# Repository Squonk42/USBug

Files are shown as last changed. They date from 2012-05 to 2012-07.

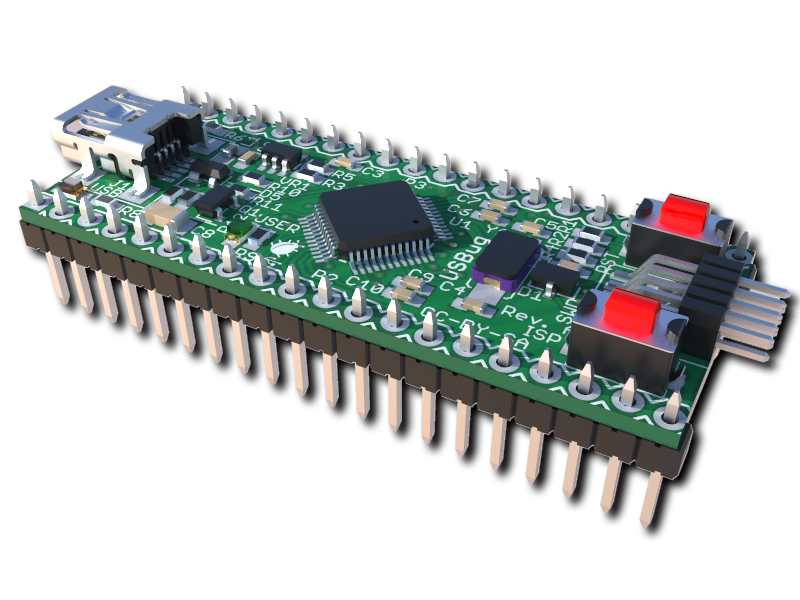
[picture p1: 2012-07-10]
images/USBug_Rendered.png

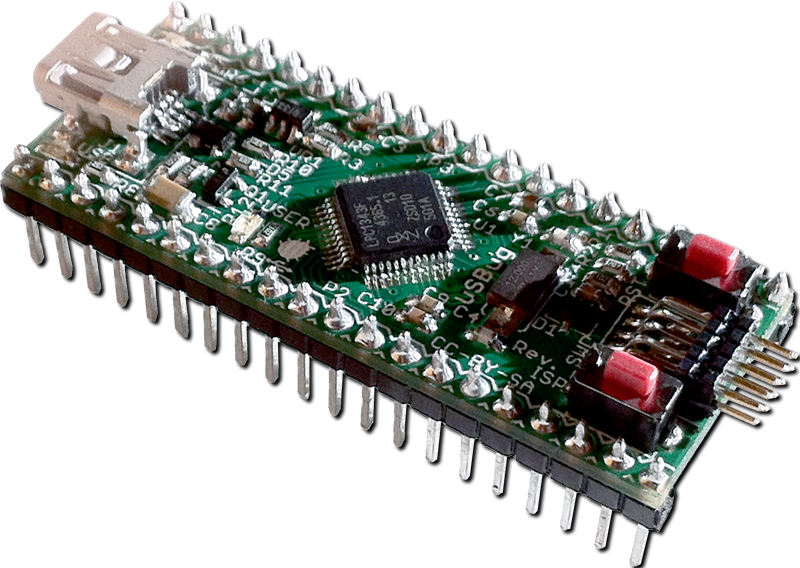
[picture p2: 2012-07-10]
images/USBug_Real.png

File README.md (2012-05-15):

USBug Development Board
=====

The USBug is a complete USB-based microcontroller development system in a very small footprint.
All programming is done via the USB port. No special programmer is needed, only a standard "Mini-B" USB cable and a Windows/Linux PC or a Macintosh with a USB port are required.

Key features:
 - Fully Open-Source Hardware & Software (CC-BY-SA, GPL)
 - Drag & Drop firmware, just use it as an USB Memory Stick!
 - No Loader application, the bootloader resides in ROM (unereasable)
 - Works with Mac OS X, Linux & Windows
 - Standard ARM SWD debug/trace connector
 - ARM "Cortex M3" 32-bit processor, up to 72 MHz, up to 64 kB Flash, up to 10 kB SRAM
 - Up to 42 GPIO pins, 1xUSB device, 1xUART, 1xI2C, 1xSPI interfaces
 - 2x32-bit, 2x16-bit, 1xWatchdog timers
 - 10 Bit ADC with up to 8 inputs
 - Tiny size: 2" x 0.8" (50 mm x 20 mm), only 0.244" (6.2 mm) thick (w/o header pins)
 - Available with pins for solderless breadboard
 - Very low cost & low shipping options

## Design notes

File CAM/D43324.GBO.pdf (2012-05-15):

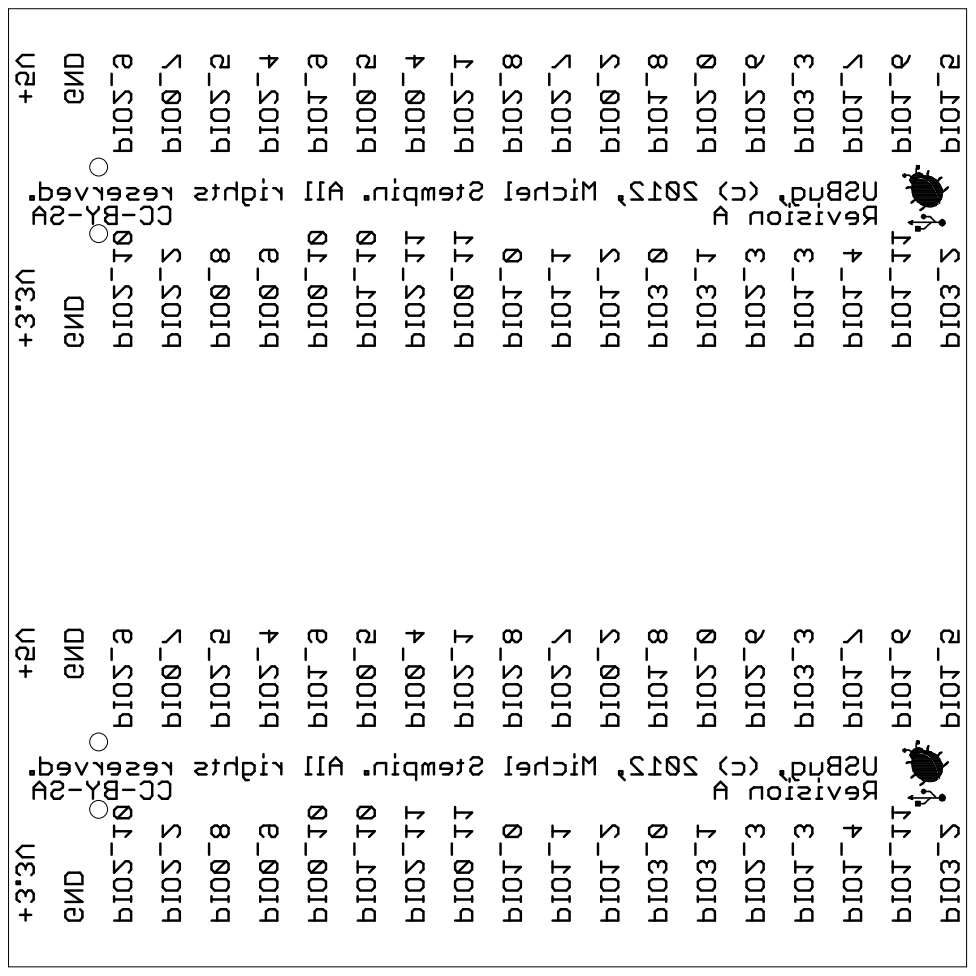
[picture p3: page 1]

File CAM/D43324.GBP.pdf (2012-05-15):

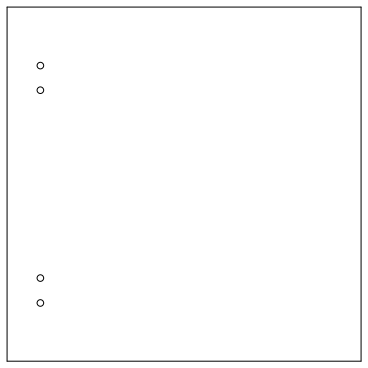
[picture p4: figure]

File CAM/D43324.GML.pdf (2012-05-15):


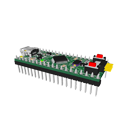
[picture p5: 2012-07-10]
images/USBug_Sketchup_s.png

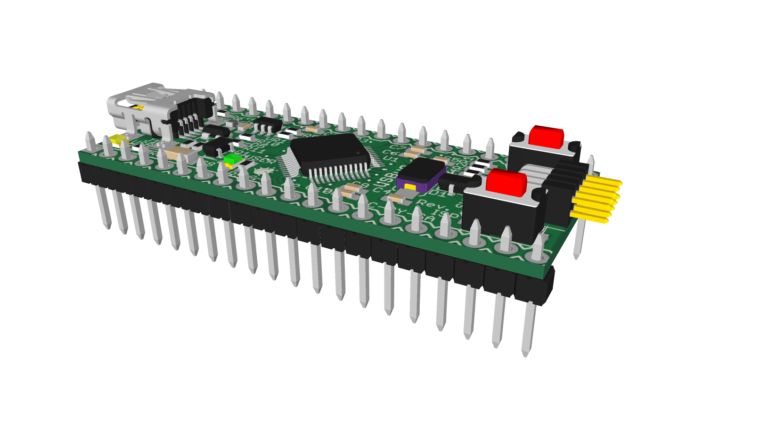
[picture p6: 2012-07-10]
images/USBug_Sketchup.png

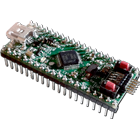
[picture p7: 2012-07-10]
images/USBug_Real_s.png

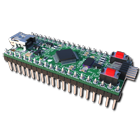
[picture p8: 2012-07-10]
images/USBug_Rendered_s.png

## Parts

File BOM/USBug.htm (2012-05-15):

Qty | Value | Device | Parts | Supplier | Supplier Part Number | Manufacturer | Manufacturer Part Number | Description | Price/1 | Price/50 | Price/100 | Price/250 | Price/500 | Price/1000
1 | 1M | RES_0603 | R12 | DigiKey | P1.0MGCT-ND | Panasonic - ECG | ERJ-3GEYJ105V | RES 1.0M OHM 1/10W 5% 0603 SMD | 0.10000 | 0.00920 | 0.00700 | 0.00520 | 0.00384 | 0.00256
2 | 1k | RES_0603 | R4, R9 | DigiKey | P1.0KGCT-ND | Panasonic - ECG | ERJ-3GEYJ102V | RES 1.0K OHM 1/10W 5% 0603 SMD | 0.10000 | 0.00920 | 0.00700 | 0.00520 | 0.00384 | 0.00256
1 | 1k5 | RES_0603 | R7 | DigiKey | P1.5KGCT-ND | Panasonic - ECG | ERJ-3GEYJ152V | RES 1.5K OHM 1/10W 5% 0603 SMD | 0.10000 | 0.00920 | 0.00700 | 0.00520 | 0.00384 | 0.00256
1 | 1u/16V | CAP_0603 | C2 | DigiKey | 587-1241-1-ND | Taiyo Yuden | EMK107B7105KA-T | CAP CER 1UF 16V 10% X7R 0603 | 0.20000 | 0.06000 | 0.04500 | 0.03252 | 0.02400 | 0.01625
1 | 2u2/10V | CAP_0603 | C3 | DigiKey | 587-2983-1-ND | Taiyo Yuden | LMK107B7225KA-T | CAP CER 2.2UF 10V 10% X7R 0603 | 0.32000 | 0.14000 | 0.11200 | 0.08000 | 0.05440 | 0.04400
1 | 10k | RES_0603 | R3 | DigiKey | P10KGCT-ND | Panasonic - ECG | ERJ-3GEYJ103V | RES 10K OHM 1/10W 5% 0603 SMD | 0.10000 | 0.00920 | 0.00700 | 0.00520 | 0.00384 | 0.00256
2 | 10n | CAP_0603 | C7, C10 | DigiKey | 445-6855-1-ND | TDK Corporation | C1608X7R1C103K | CAP CER 10000PF 16V 10% X7R 0603 | 0.24000 |  | 0.01100 | 0.00900 | 0.0770 | 0.00600
1 | 10n/500V | CAP_1206 | C8 | DigiKey | 709-1027-1-ND | Johanson Dielectrics Inc | 501R18W103KV4E | CAP CER 10000PF 500V X7R 1206 | 0.32000 |  | 0.11270 | 0.08052 | 0.05474 | 0.04428
1 | 12MHz | CRYSTAL_50X32 | Y1 | DigiKey | 644-1034-1-ND | NDK | NX5032GA-12.000000MHZ-LN-CD-1 | CRYSTAL 12.000000 MHZ 8PF SMD | 0.81000 | 0.61560 | 0.48600 |  | 0.41040
2 | 18p/50V | CAP_0603 | C4, C5 | DigiKey | 445-1272-1-ND | TDK Corporation | C1608C0G1H180J | CAP CER 18PF 50V 5% NP0 0603 | 0.30000 |  | 0.01380 | 0.01124 | 0.00962 | 0.00750
2 | 20K | RES_0603 | R1, R2 | DigiKey | P20KGCT-ND | Panasonic - ECG | ERJ-3GEYJ203V | RES 20K OHM 1/10W 5% 0603 SMD | 0.10000 | 0.00920 | 0.00700 | 0.00520 | 0.00384 | 0.00256
2 | 33R | RES_0603 | R10, R11 | DigiKey | P33GCT-ND | Panasonic - ECG | ERJ-3GEYJ330V | RES 33 OHM 1/10W 5% 0603 SMD | 0.10000 | 0.00920 | 0.00700 | 0.00520 | 0.00384 | 0.00256
1 | 100k | RES_0603 | R5 | DigiKey | P100KGCT-ND | Panasonic - ECG | ERJ-3GEYJ104V | RES 100K OHM 1/10W 5% 0603 SMD | 0.10000 | 0.00920 | 0.00700 | 0.00520 | 0.00384 | 0.00256
3 | 100n | CAP_0603 | C1, C6, C9 | DigiKey | 478-1239-1-ND | AVX Corporation | 0603YC104KAT2A | CAP CER 0.1UF 16V 10% X7R 0603 | 0.10000 |  | 0.00940 | 0.00764 | 0.00654 | 0.00500
2 | 150R | RES_0603 | R6, R8 | DigiKey | P150GCT-ND | Panasonic - ECG | ERJ-3GEYJ151V | RES 150 OHM 1/10W 5% 0603 SMD | 0.10000 | 0.00920 | 0.00700 | 0.00520 | 0.00384 | 0.00256
1 | BAT54C | BAT54C | D1 | DigiKey | BAT54C-FDICT-ND | Diodes Inc | BAT54C-7-F | DIODE SCHOTTKY DUAL 30V SOT23-3 | 0.20000 |  | 0.12050 | 0.07100 | 0.05890 | 0.04017
1 | BLM18EG601SN1D | FERRITE_BEAD0603 | L1 | DigiKey | 490-3994-1-ND | Murata Electronics North America | BLM18EG601SN1D | FILTER CHIP 600 OHM 500MA 0603 | 0.38000 | 0.21840 | 0.18200 | 0.13652 | 0.11648 | 0.09100
1 | BSS84-7-F | BSS84-7-F | Q1 | DigiKey | BSS84-FDICT-ND | Diodes Inc | BSS84-7-F | MOSFET P-CH 50V 130MA SOT23-3 | 0.39000 |  | 0.16380 | 0.11580 | 0.09270 | 0.07110
1 | FTSH-105-01-L-DH | FTSH-105-01-L-DH | P1 | DigiKey | SAM1160-05-ND | Samtec Inc | FTSH-105-01-L-DH | CONN HEADR 10POS DL .05" R/A SMD | 3.84000 |  | 2.81600 |  | 2.24000 | 1.82400
1 | ISP | SPST_SWITCH | S2 | DigiKey | 679-2307-1-ND | APEM Components, LLC | ADTSM32RVTR | SWITCH TACTILE SPST-NO 0.05A 12V | 0.86000 | 0.70100 | 0.61990 | 0.56596 | 0.53900
1 | LEFT | HEADER_1X20_LOCK | P2 | DigiKey | WM6420-ND | Molex Connector Corporation | 22-28-4200 | CONN HEADER 20POS .100 VERT TIN | 0.64000 |  | 0.47160 |  | 0.37276 | 0.32000
1 | LPC1343FBD48 | LPC1343FBD48 | U1 | DigiKey | 568-4945-ND | NXP Semiconductors | LPC1343FBD48,151 | IC MCU 32BIT 32KB FLASH 48LQFP | 4.51000 |  | 3.30050 | 2.97852 | 2.67260 | 2.25400
1 | MIC5225-3.3YM5 | MIC5225-3.3YM5 | VR1 | DigiKey | 576-2980-1-ND | Micrel Inc | MIC5225-3.3YM5 TR | IC REG 3.3V SOT23-5 | 0.75000 |  | 0.50000 | 0.37500 | 0.35000
1 | MINI-B USB | MINI-B_USBUX60-MB-5ST | J1 | DigiKey | H2959CT-ND | Hirose Electric Co Ltd | UX60-MB-5ST | CONN RECEPT MINI USB2.0 5POS | 1.25000 | 0.82500 | 0.74250 | 0.62700 | 0.52800
1 | POWER | LED_0805 | D2 | DigiKey | 350-2038-1-ND | Dialight | 598-8110-107F | LED TOPLED LED ALINGAP RED CLEAR 0805 SMD | 0.39000 |  | 0.16430 | 0.11624 | 0.09920 | 0.07750
1 | PRTR5V0U2X | PRTR5V0U2X | D5 | DigiKey | 568-4140-1-ND | NXP Semiconductors | PRTR5V0U2X,215 | DIODE ESD PROTECTION SOT143B | 0.57000 |  | 0.35780 | 0.31036 | 0.26286 | 0.20265
1 | RESET | SPST_SWITCH | S1 | DigiKey | 679-2307-1-ND | APEM Components, LLC | ADTSM32RVTR | SWITCH TACTILE SPST-NO 0.05A 12V | 0.86000 | 0.70100 | 0.61990 | 0.56596 | 0.53900
1 | RIGHT | HEADER_1X20_LOCK | P3 | DigiKey | WM6420-ND | Molex Connector Corporation | 22-28-4200 | CONN HEADER 20POS .100 VERT TIN | 0.64000 |  | 0.47160 |  | 0.37276 | 0.32000
1 | USB | LED_0805 | D3 | DigiKey | 350-2032-1-ND | Dialight | 598-8140-107F | LED ALINGAP YLW CLEAR 0805 SMD | 0.46000 |  | 0.19610 | 0.13876 | 0.11840 | 0.09250
1 | USBUG | USBUG | LOGO
1 | USER | LED_0805 | D4 | DigiKey | 350-2035-1-ND | Dialight | 598-8170-107F | LED ALINGAP GREEN CLEAR 0805 SMD | 0.41000 |  | 0.17490 | 0.12376 | 0.10560 | 0.08250

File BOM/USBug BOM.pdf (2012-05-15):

# USBug

Qty | Value | Device | Parts | Supplier | Supplier Part Number | Supplier Part Number | Manufacturer | Manufacturer Part Number | Description | Price/1 | Price/50 | Price/100 | Price/250 | Price/500 | Price/1000 | Total/1
3 | 100n | CAP_0603 | C1, C6, C9 | DigiKey | 478-1239-1-ND | 478-1239-6-ND | AVX Corporation | 0603YC104KAT2A | CAP CER 0.1UF 16V 10% X7R 0603 | $0,10000 | | $0,00940 | $0,00764 | $0,00654 | $0,00500 | $0,30000
1 | 1u/16V | CAP_0603 | C2 | DigiKey | 587-1241-1-ND | 587-1241-6-ND | Taiyo Yuden | EMK107B7105KA-T | CAP CER 1UF 16V 10% X7R 0603 | $0,20000 | $0,06000 | $0,04500 | $0,03252 | $0,02400 | $0,01625 | $0,20000
1 | 2u2/10V | CAP_0603 | C3 | DigiKey | 587-2983-1-ND | 587-2983-6-ND | Taiyo Yuden | LMK107B7225KA-T | CAP CER 2.2UF 10V 10% X7R 0603 | $0,32000 | $0,14000 | $0,11200 | $0,08000 | $0,05440 | $0,04400 | $0,32000
2 | 18p | CAP_0603 | C4, C5 | DigiKey | 445-1272-1-ND | 445-1272-6-ND | TDK Corporation | C1608C0G1H180J | CAP CER 18PF 50V 5% NP0 0603 | $0,30000 | | $0,01380 | $0,01124 | $0,00962 | $0,00750 | $0,60000
2 | 10n | CAP_0603 | C7, C10 | DigiKey | 445-6855-1-ND | 445-6855-6-ND | TDK Corporation | C1608X7R1C103K | CAP CER 10000PF 16V 10% X7R 0603 | $0,24000 | | $0,01100 | $0,00900 | $0,00770 | $0,00600 | $0,48000
1 | 10n/500V | CAP_1206 | C8 | DigiKey | 709-1027-1-ND | 709-1027-6-ND | Johanson Dielectrics Inc | 501R18W103KV4E | CAP CER 10000PF 500V X7R 1206 | $0,32000 | | $0,11270 | $0,08052 | $0,05474 | $0,04428 | $0,32000
1 | BAT54C | BAT54C | D1 | DigiKey | BAT54C-FDICT-ND | BAT54C-FDIDKR-ND | Diodes Inc | BAT54C-7-F | DIODE SCHOTTKY DUAL 30V SOT23-3 | $0,20000 | | $0,12050 | $0,07100 | $0,05890 | $0,04017 | $0,20000
1 | POWER | LED_0805 | D2 | DigiKey | 350-2038-1-ND | 350-2038-1-ND | Dialight | 598-8110-107F | LED ALINGAP RED CLEAR 0805 SMD | $0,39000 | | $0,16430 | $0,11624 | $0,09920 | $0,07750 | $0,39000
1 | USB | LED_0805 | D3 | DigiKey | 350-2032-1-ND | 350-2032-1-ND | Dialight | 598-8140-107F | LED ALINGAP YLW CLEAR 0805 SMD | $0,46000 | | $0,19610 | $0,13876 | $0,11840 | $0,09250 | $0,46000
1 | USER | LED_0805 | D4 | DigiKey | 350-2035-1-ND | 350-2035-1-ND | Dialight | 598-8170-107F | LED ALINGAP GREEN CLEAR 0805 SMD | $0,41000 | | $0,17490 | $0,12376 | $0,10560 | $0,08250 | $0,41000
1 | PRTR5V0U2X | PRTR5V0U2X | D5 | DigiKey | 568-4140-1-ND | 568-4140-6-ND | NXP Semiconductors | PRTR5V0U2X,215 | DIODE ESD PROTECTION SOT143B | $0,57000 | | $0,35780 | $0,31036 | $0,26286 | $0,20265 | $0,57000
1 | MINI-B USB | MINI-B_USBUX60-MB-5ST | J1 | DigiKey | H2959CT-ND | H2959DKR-ND | Hirose Electric Co Ltd | UX60-MB-5ST | CONN RECEPT MINI USB2.0 5POS | $1,25000 | $0,82500 | $0,74250 | $0,62700 | $0,52800 | $0,52800 | $1,25000
1 | BLM18EG601SN1D | FERRITE_BEAD0603 | L1 | DigiKey | 490-3994-1-ND | 490-3994-6-ND | Murata Electronics North America | BLM18EG601SN1D | FILTER CHIP 600 OHM 500MA 0603 | $0,38000 | $0,21840 | $0,18200 | $0,13652 | $0,11648 | $0,09100 | $0,38000
1 | FTSH-105-01-L-DH | FTSH-105-01-L-DH | P1 | DigiKey | SAM1160-05-ND | SAM1160-05-ND | Samtec Inc | FTSH-105-01-L-DH | CONN HEADR 10POS DL .05" R/A SMD | $3,84000 | | $2,81600 | | $2,24000 | $1,82400 | $3,84000
1 | LEFT | HEADER_1X20_LOCK | P2 | DigiKey | WM6420-ND | WM6420-ND | Molex Connector Corporation | 22-28-4200 | CONN HEADER 20POS .100 VERT TIN | $0,64000 | | $0,47160 | | $0,37276 | $0,32000 | $0,64000
1 | RIGHT | HEADER_1X20_LOCK | P3 | DigiKey | WM6420-ND | WM6420-ND | Molex Connector Corporation | 22-28-4200 | CONN HEADER 20POS .100 VERT TIN | $0,64000 | | $0,47160 | | $0,37276 | $0,32000 | $0,64000
1 | BSS84-7-F | BSS84-7-F | Q1 | DigiKey | BSS84-FDICT-ND | BSS84-FDIDKR-ND | Diodes Inc | BSS84-7-F | MOSFET P-CH 50V 130MA SOT23-3 | $0,39000 | | $0,16380 | $0,11580 | $0,09270 | $0,07110 | $0,39000
2 | 20K | RES_0603 | R1, R2 | DigiKey | P20KGCT-ND | P20KGDKR-ND | Panasonic - ECG | ERJ-3GEYJ203V | RES 20K OHM 1/10W 5% 0603 SMD | $0,10000 | $0,00920 | $0,00700 | $0,00520 | $0,00384 | $0,00256 | $0,20000
2 | 33R | RES_0603 | R10, R11 | DigiKey | P33GCT-ND | P33GDKR-ND | Panasonic - ECG | ERJ-3GEYJ330V | RES 33 OHM 1/10W 5% 0603 SMD | $0,10000 | $0,00920 | $0,00700 | $0,00520 | $0,00384 | $0,00256 | $0,20000
1 | 1M | RES_0603 | R12 | DigiKey | P1.0MGCT-ND | P1.0MGDKR-ND | Panasonic - ECG | ERJ-3GEYJ105V | RES 1.0M OHM 1/10W 5% 0603 SMD | $0,10000 | $0,00920 | $0,00700 | $0,00520 | $0,00384 | $0,00256 | $0,10000
1 | 10k | RES_0603 | R3 | DigiKey | P10KGCT-ND | P10KGDKR-ND | Panasonic - ECG | ERJ-3GEYJ103V | RES 10K OHM 1/10W 5% 0603 SMD | $0,10000 | $0,00920 | $0,00700 | $0,00520 | $0,00384 | $0,00256 | $0,10000
2 | 1k | RES_0603 | R4, R9 | DigiKey | P1.0KGCT-ND | P1.0KGDKR-ND | Panasonic - ECG | ERJ-3GEYJ102V | RES 1.0K OHM 1/10W 5% 0603 SMD | $0,10000 | $0,00920 | $0,00700 | $0,00520 | $0,00384 | $0,00256 | $0,20000
1 | 100k | RES_0603 | R5 | DigiKey | P100KGCT-ND | P100KGDKR-ND | Panasonic - ECG | ERJ-3GEYJ104V | RES 100K OHM 1/10W 5% 0603 SMD | $0,10000 | $0,00920 | $0,00700 | $0,00520 | $0,00384 | $0,00256 | $0,10000
2 | 150R | RES_0603 | R6, R8 | DigiKey | P150GCT-ND | P150GDKR-ND | Panasonic - ECG | ERJ-3GEYJ151V | RES 150 OHM 1/10W 5% 0603 SMD | $0,10000 | $0,00920 | $0,00700 | $0,00520 | $0,00384 | $0,00256 | $0,20000
1 | 1k5 | RES_0603 | R7 | DigiKey | P1.5KGCT-ND | P1.5KGDKR-ND | Panasonic - ECG | ERJ-3GEYJ152V | RES 1.5K OHM 1/10W 5% 0603 SMD | $0,10000 | $0,00920 | $0,00700 | $0,00520 | $0,00384 | $0,00256 | $0,10000
1 | RESET | SPST_SWITCH | S1 | DigiKey | 679-2307-1-ND | 679-2307-6-ND | APEM Components, LLC | ADTSM32RVTR | SWITCH TACTILE SPST-NO 0.05A 12V | $0,86000 | $0,00920 | $0,00700 | $0,00520 | $0,00384 | $0,00256 | $0,86000
1 | ISP | SPST_SWITCH | S2 | DigiKey | 679-2307-1-ND | 679-2307-6-ND | APEM Components, LLC | ADTSM32RVTR | SWITCH TACTILE SPST-NO 0.05A 12V | $0,86000 | $0,70100 | $0,61990 | $0,56596 | $0,53900 | $0,53900 | $0,86000
1 | LPC1343FBD48 | LPC1343FBD48 | U1 | DigiKey | 568-4945-ND | 568-4945-ND | NXP Semiconductors | LPC1343FBD48,151 | IC MCU 32BIT 32KB FLASH 48LQFP | $4,51000 | | $3,30050 | $2,97852 | $2,67260 | $2,25400 | $4,51000
1 | MIC5225-3.3YM5 | MIC5225-3.3YM5 | VR1 | DigiKey | 576-2980-1-ND | 576-2980-6-ND | Micrel Inc | MIC5225-3.3YM5 TR | IC REG 3.3V SOT23-5 | $0,75000 | | $0,50000 | $0,37500 | $0,35000 | $0,35000 | $0,75000
1 | 12MHz | CRYSTAL_50X32 | Y1 | DigiKey | 644-1034-1-ND | 644-1034-6-ND | NDK | NX5032GA-12.000000MHZ-LN-CD-1 | CRYSTAL 12.000000 MHZ 8PF SMD | $0,81000 | $0,61560 | $0,48600 | | $0,41040 | $0,41040 | $0,81000
TOTAL | | | | | | | | | | | | | | | | $19,88000
Michel Stempin | Page 1 | 15/05/2012

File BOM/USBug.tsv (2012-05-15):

Key | Supplier | Supplier Part Number | Manufacturer | Manufacturer Part Number | Description | Price/1 | Price/50 | Price/100 | Price/250 | Price/500 | Price/1000
FERRITE_BEAD0603:BLM18EG601SN1D | DigiKey | 490-3994-1-ND | Murata Electronics North America | BLM18EG601SN1D | FILTER CHIP 600 OHM 500MA 0603 | 0.38000 | 0.21840 | 0.18200 | 0.13652 | 0.11648 | 0.09100
BSS84-7-F | DigiKey | BSS84-FDICT-ND | Diodes Inc | BSS84-7-F | MOSFET P-CH 50V 130MA SOT23-3 | 0.39000 |  | 0.16380 | 0.11580 | 0.09270 | 0.07110
FTSH-105-01-L-DH | DigiKey | SAM1160-05-ND | Samtec Inc | FTSH-105-01-L-DH | CONN HEADR 10POS DL .05" R/A SMD | 3.84000 |  | 2.81600 |  | 2.24000 | 1.82400
MIC5225-3.3YM5 | DigiKey | 576-2980-1-ND | Micrel Inc | MIC5225-3.3YM5 TR | IC REG 3.3V SOT23-5 | 0.75000 |  | 0.50000 | 0.37500 | 0.35000
PRTR5V0U2X | DigiKey | 568-4140-1-ND | NXP Semiconductors | PRTR5V0U2X,215 | DIODE ESD PROTECTION SOT143B | 0.57000 |  | 0.35780 | 0.31036 | 0.26286 | 0.20265
CRYSTAL_50X32:12MHz | DigiKey | 644-1034-1-ND | NDK | NX5032GA-12.000000MHZ-LN-CD-1 | CRYSTAL 12.000000 MHZ 8PF SMD | 0.81000 | 0.61560 | 0.48600 |  | 0.41040
MINI-B_USBUX60-MB-5ST:MINI-B USB | DigiKey | H2959CT-ND | Hirose Electric Co Ltd | UX60-MB-5ST | CONN RECEPT MINI USB2.0 5POS | 1.25000 | 0.82500 | 0.74250 | 0.62700 | 0.52800
HEADER_1X20_LOCK:LEFT | DigiKey | WM6420-ND | Molex Connector Corporation | 22-28-4200 | CONN HEADER 20POS .100 VERT TIN | 0.64000 |  | 0.47160 |  | 0.37276 | 0.32000
HEADER_1X20_LOCK:RIGHT | DigiKey | WM6420-ND | Molex Connector Corporation | 22-28-4200 | CONN HEADER 20POS .100 VERT TIN | 0.64000 |  | 0.47160 |  | 0.37276 | 0.32000
SPST_SWITCH:ISP | DigiKey | 679-2307-1-ND | APEM Components, LLC | ADTSM32RVTR | SWITCH TACTILE SPST-NO 0.05A 12V | 0.86000 | 0.70100 | 0.61990 | 0.56596 | 0.53900
SPST_SWITCH:RESET | DigiKey | 679-2307-1-ND | APEM Components, LLC | ADTSM32RVTR | SWITCH TACTILE SPST-NO 0.05A 12V | 0.86000 | 0.70100 | 0.61990 | 0.56596 | 0.53900
BAT54C | DigiKey | BAT54C-FDICT-ND | Diodes Inc | BAT54C-7-F | DIODE SCHOTTKY DUAL 30V SOT23-3 | 0.20000 |  | 0.12050 | 0.07100 | 0.05890 | 0.04017
LED_0805:POWER | DigiKey | 350-2038-1-ND | Dialight | 598-8110-107F | LED TOPLED LED ALINGAP RED CLEAR 0805 SMD | 0.39000 |  | 0.16430 | 0.11624 | 0.09920 | 0.07750
LED_0805:USB | DigiKey | 350-2032-1-ND | Dialight | 598-8140-107F | LED ALINGAP YLW CLEAR 0805 SMD | 0.46000 |  | 0.19610 | 0.13876 | 0.11840 | 0.09250
LED_0805:USER | DigiKey | 350-2035-1-ND | Dialight | 598-8170-107F | LED ALINGAP GREEN CLEAR 0805 SMD | 0.41000 |  | 0.17490 | 0.12376 | 0.10560 | 0.08250
LPC11U12FBD48 | DigiKey | 568-8582-ND | NXP Semiconductors | LPC11U12FBD48/201, | IC MCU 32BIT 16K 48LQFP | 3.61000 |  | 2.64450 | 2.38652 | 2.14140 | 1.80600
RES_0603:1M | DigiKey | P1.0MGCT-ND | Panasonic - ECG | ERJ-3GEYJ105V | RES 1.0M OHM 1/10W 5% 0603 SMD | 0.10000 | 0.00920 | 0.00700 | 0.00520 | 0.00384 | 0.00256
RES_0603:1k5 | DigiKey | P1.5KGCT-ND | Panasonic - ECG | ERJ-3GEYJ152V | RES 1.5K OHM 1/10W 5% 0603 SMD | 0.10000 | 0.00920 | 0.00700 | 0.00520 | 0.00384 | 0.00256
RES_0603:20K | DigiKey | P20KGCT-ND | Panasonic - ECG | ERJ-3GEYJ203V | RES 20K OHM 1/10W 5% 0603 SMD | 0.10000 | 0.00920 | 0.00700 | 0.00520 | 0.00384 | 0.00256
RES_0603:10k | DigiKey | P10KGCT-ND | Panasonic - ECG | ERJ-3GEYJ103V | RES 10K OHM 1/10W 5% 0603 SMD | 0.10000 | 0.00920 | 0.00700 | 0.00520 | 0.00384 | 0.00256
RES_0603:1k | DigiKey | P1.0KGCT-ND | Panasonic - ECG | ERJ-3GEYJ102V | RES 1.0K OHM 1/10W 5% 0603 SMD | 0.10000 | 0.00920 | 0.00700 | 0.00520 | 0.00384 | 0.00256
RES_0603:100k | DigiKey | P100KGCT-ND | Panasonic - ECG | ERJ-3GEYJ104V | RES 100K OHM 1/10W 5% 0603 SMD | 0.10000 | 0.00920 | 0.00700 | 0.00520 | 0.00384 | 0.00256
RES_0603:150R | DigiKey | P150GCT-ND | Panasonic - ECG | ERJ-3GEYJ151V | RES 150 OHM 1/10W 5% 0603 SMD | 0.10000 | 0.00920 | 0.00700 | 0.00520 | 0.00384 | 0.00256
RES_0603:33R | DigiKey | P33GCT-ND | Panasonic - ECG | ERJ-3GEYJ330V | RES 33 OHM 1/10W 5% 0603 SMD | 0.10000 | 0.00920 | 0.00700 | 0.00520 | 0.00384 | 0.00256
CAP_0603:100n | DigiKey | 478-1239-1-ND | AVX Corporation | 0603YC104KAT2A | CAP CER 0.1UF 16V 10% X7R 0603 | 0.10000 |  | 0.00940 | 0.00764 | 0.00654 | 0.00500
CAP_0603:10n | DigiKey | 445-6855-1-ND | TDK Corporation | C1608X7R1C103K | CAP CER 10000PF 16V 10% X7R 0603 | 0.24000 |  | 0.01100 | 0.00900 | 0.0770 | 0.00600
CAP_0603:1u/16V | DigiKey | 587-1241-1-ND | Taiyo Yuden | EMK107B7105KA-T | CAP CER 1UF 16V 10% X7R 0603 | 0.20000 | 0.06000 | 0.04500 | 0.03252 | 0.02400 | 0.01625
CAP_0603:2u2/10V | DigiKey | 587-2983-1-ND | Taiyo Yuden | LMK107B7225KA-T | CAP CER 2.2UF 10V 10% X7R 0603 | 0.32000 | 0.14000 | 0.11200 | 0.08000 | 0.05440 | 0.04400
CAP_0603:18p/50V | DigiKey | 445-1272-1-ND | TDK Corporation | C1608C0G1H180J | CAP CER 18PF 50V 5% NP0 0603 | 0.30000 |  | 0.01380 | 0.01124 | 0.00962 | 0.00750
CAP_1206:10n/500V | DigiKey | 709-1027-1-ND | Johanson Dielectrics Inc | 501R18W103KV4E | CAP CER 10000PF 500V X7R 1206 | 0.32000 |  | 0.11270 | 0.08052 | 0.05474 | 0.04428
LPC1343FBD48 | DigiKey | 568-4945-ND | NXP Semiconductors | LPC1343FBD48,151 | IC MCU 32BIT 32KB FLASH 48LQFP | 4.51000 |  | 3.30050 | 2.97852 | 2.67260 | 2.25400

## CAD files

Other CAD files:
eagleUp/USBug.skp

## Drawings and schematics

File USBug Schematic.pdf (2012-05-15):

A

A

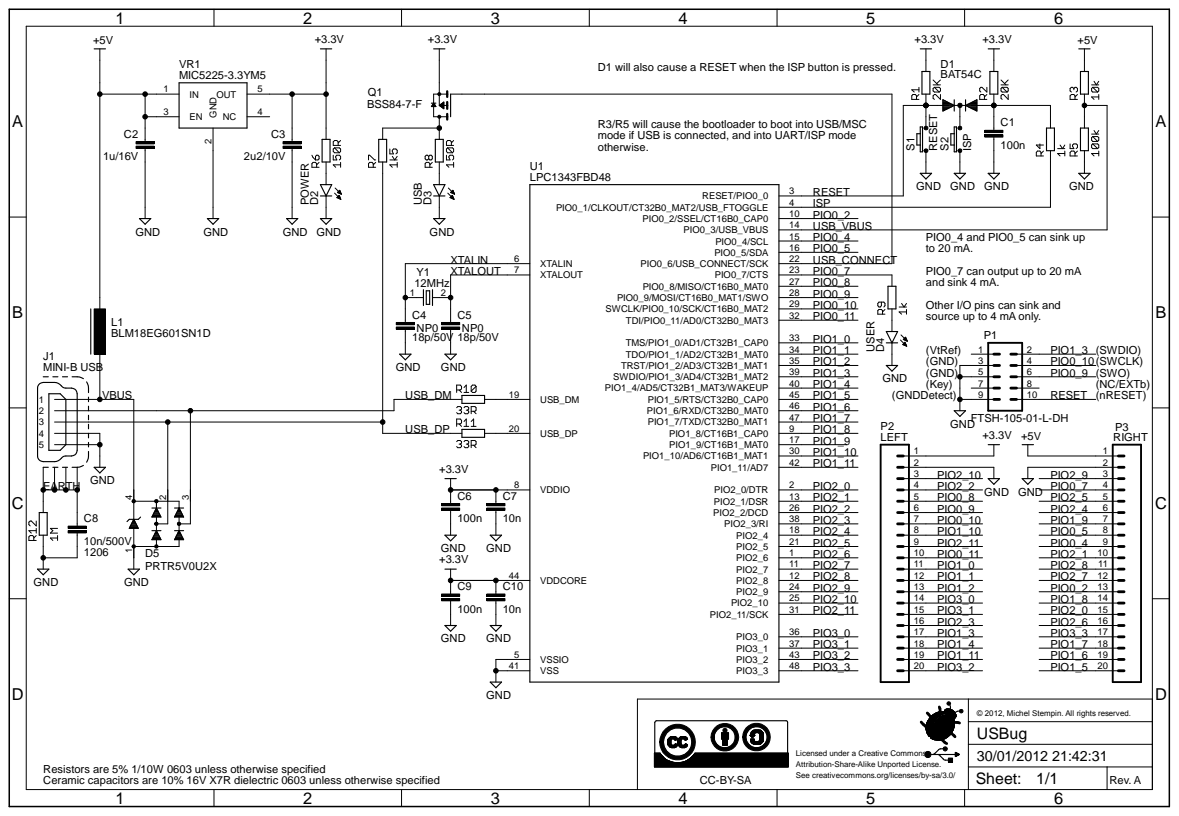
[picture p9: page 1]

D1 will also cause a RESET when the ISP button is pressed.

R3/R5 will cause the bootloader to boot into USB/MS
mode if USB is connected, and into UART/ISP mode
otherwise.

PIO0_4 and PIO0_5 can sink up
PIO0_7 can output up to 20 mA
and sink 4 mA.
Other I/O pins can sink and
source up to 4 mA only.

Licensed under a Creative Commons
Attribution-Share-Alike Unported License.
See creativecommons.org/licenses/by-sa/3.0/

Resistors are 5% 1/10W 0603 unless otherwise specified
Ceramic capacitors are 10% 16V X7R dielectric 0603 unless otherwise specified

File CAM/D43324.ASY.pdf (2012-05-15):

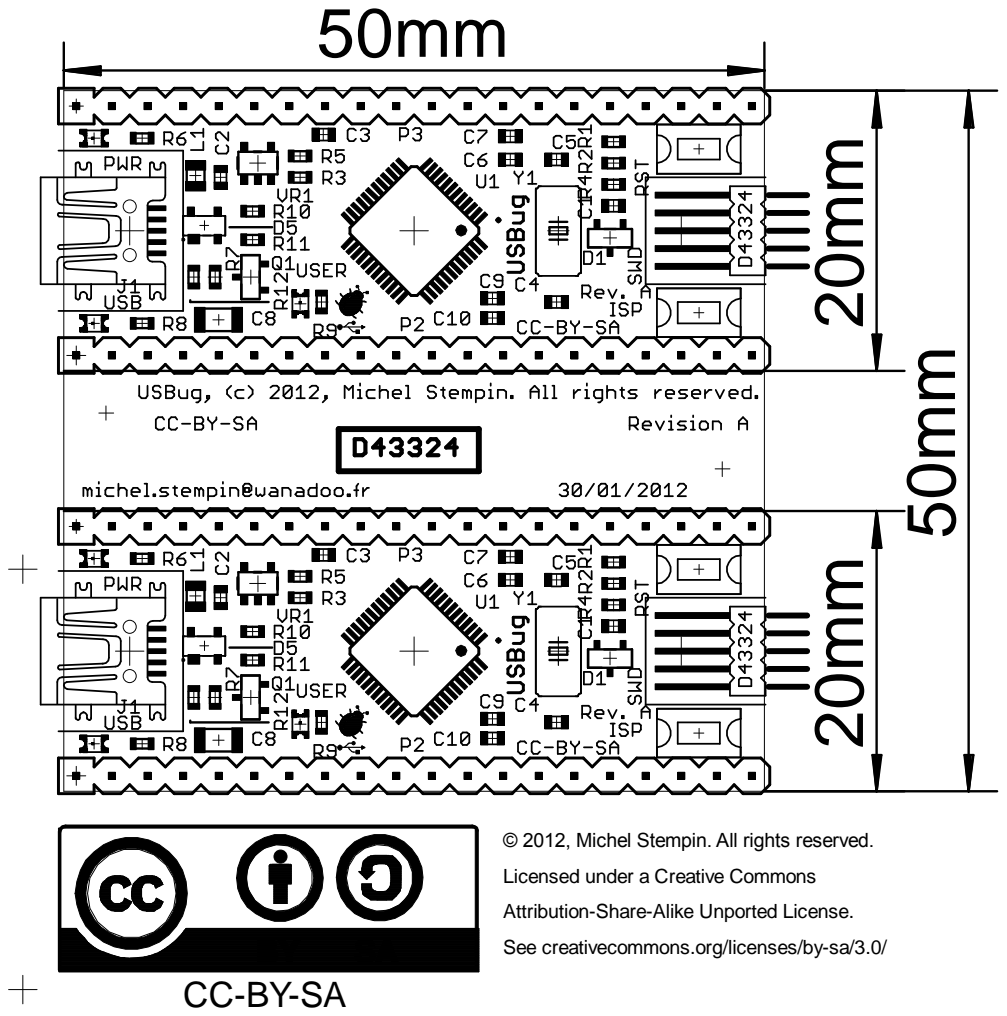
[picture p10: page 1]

© 2012, Michel Stempin. All rights reserved.
Licensed under a Creative Commons
Attribution-Share-Alike Unported License.
See creativecommons.org/licenses/by-sa/3.0/

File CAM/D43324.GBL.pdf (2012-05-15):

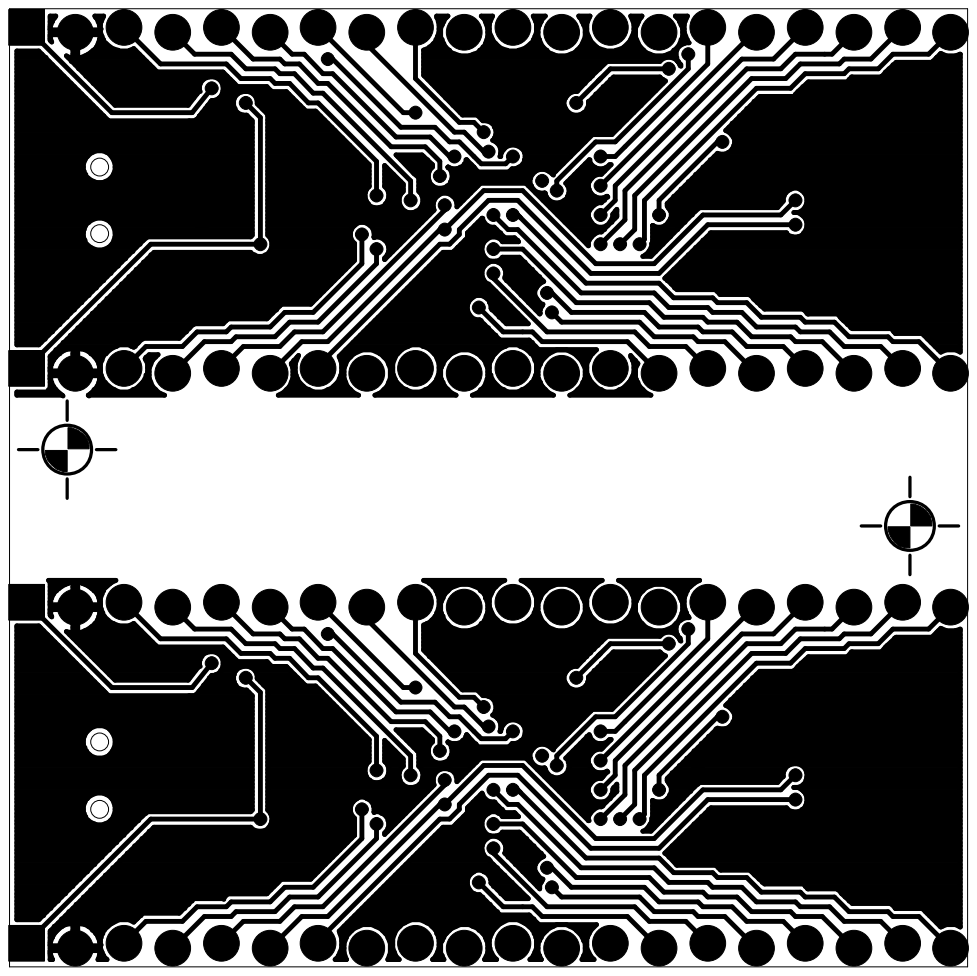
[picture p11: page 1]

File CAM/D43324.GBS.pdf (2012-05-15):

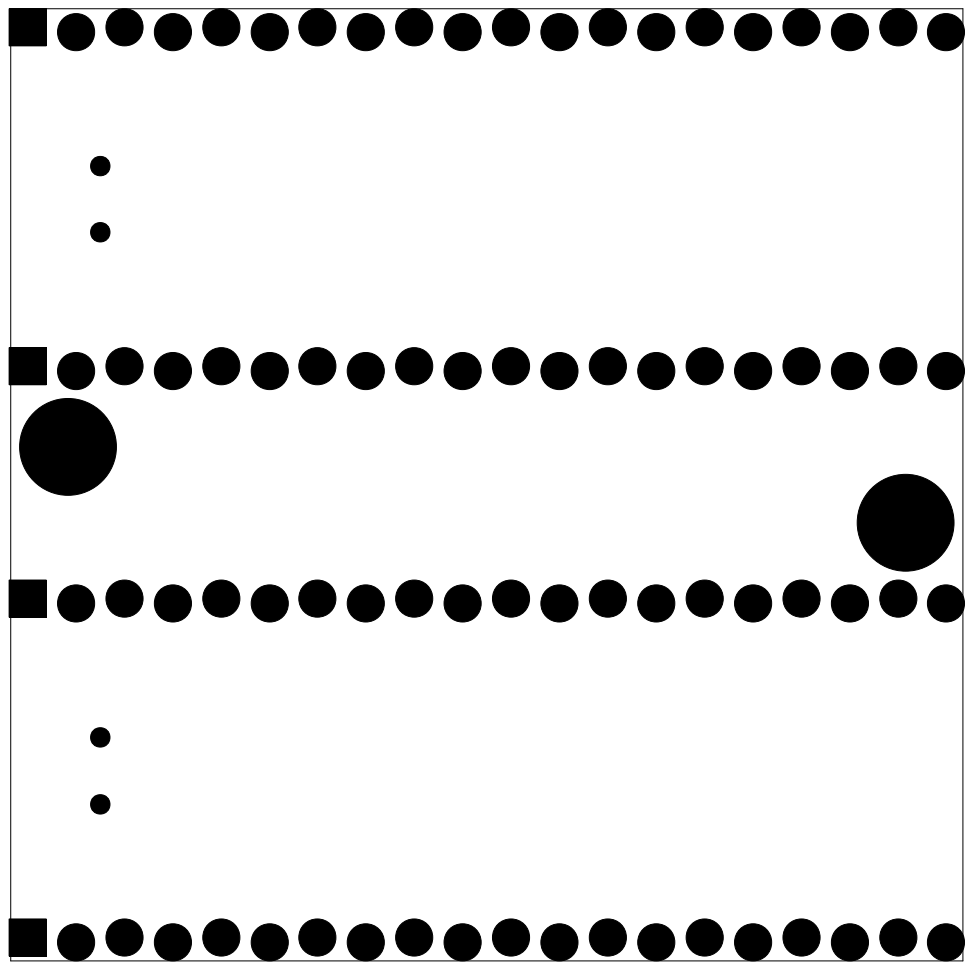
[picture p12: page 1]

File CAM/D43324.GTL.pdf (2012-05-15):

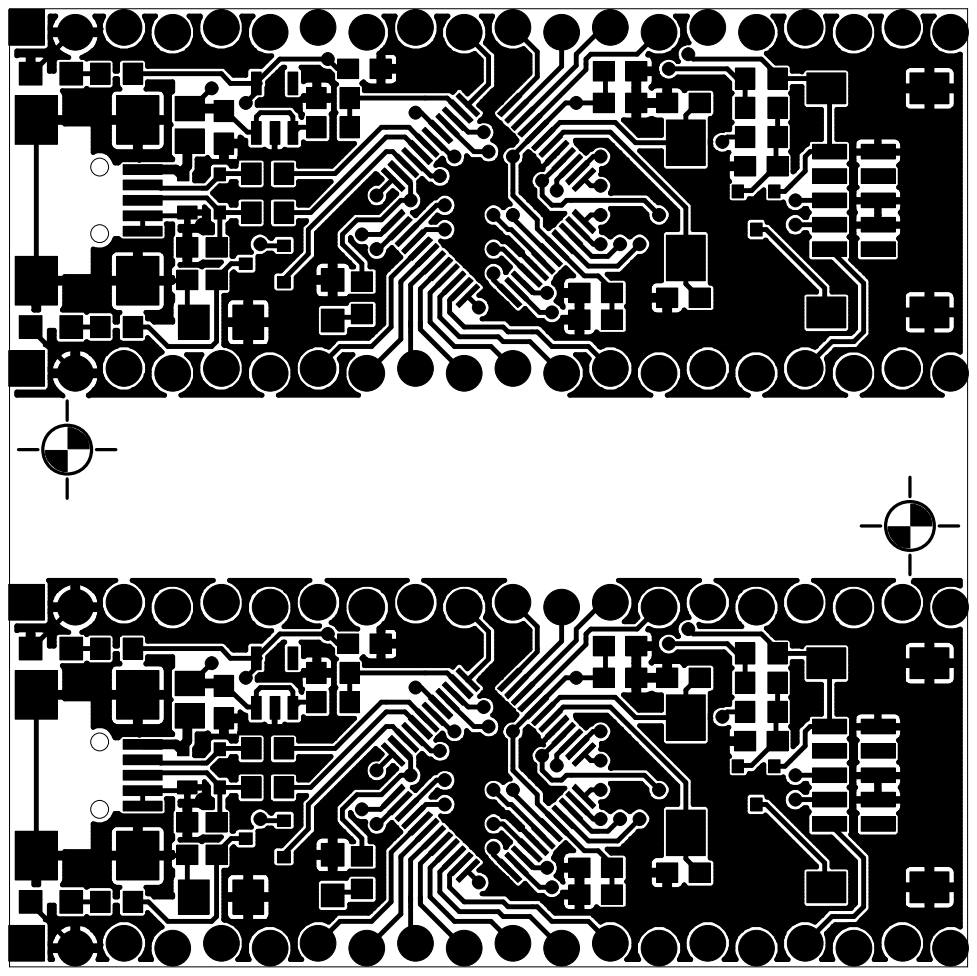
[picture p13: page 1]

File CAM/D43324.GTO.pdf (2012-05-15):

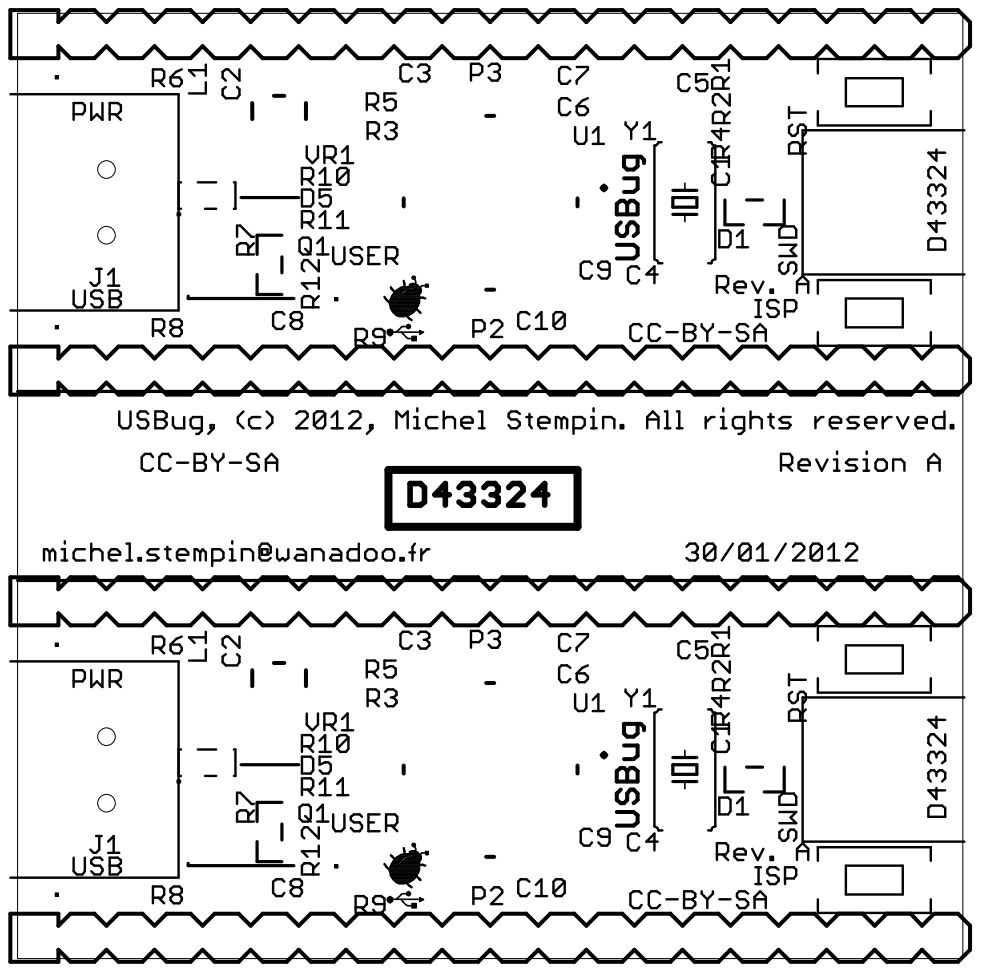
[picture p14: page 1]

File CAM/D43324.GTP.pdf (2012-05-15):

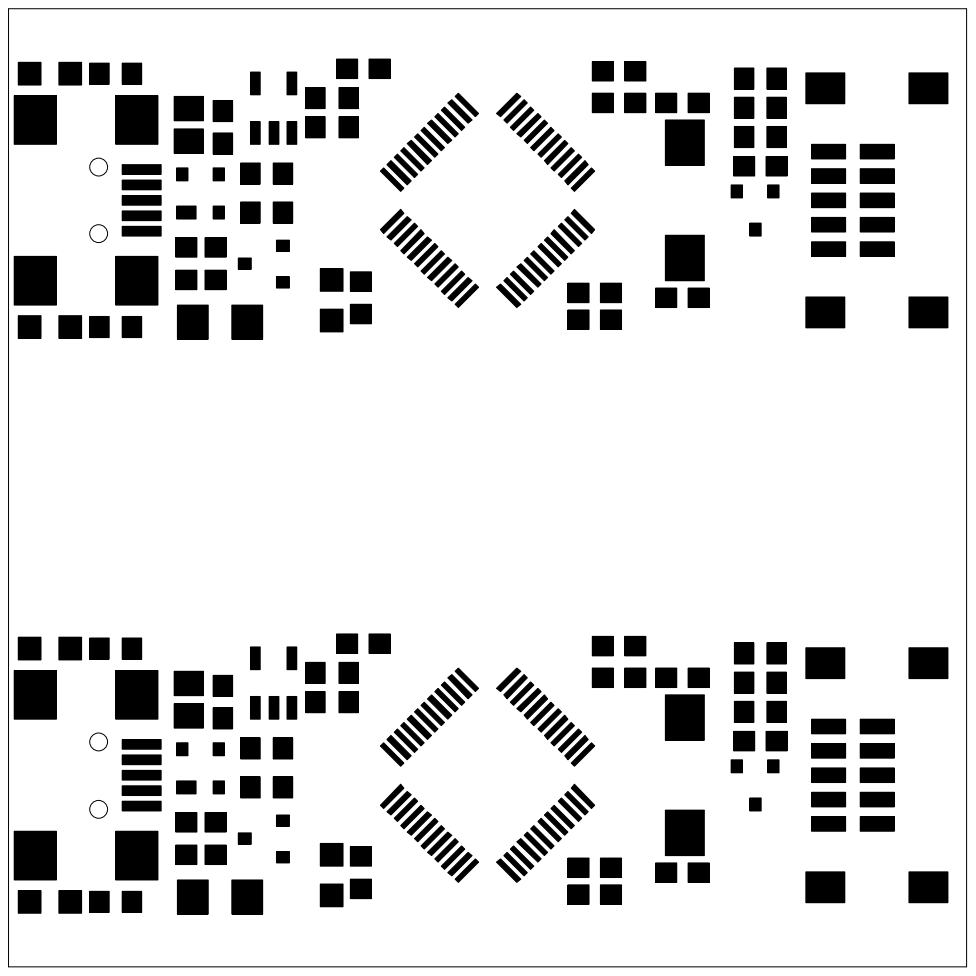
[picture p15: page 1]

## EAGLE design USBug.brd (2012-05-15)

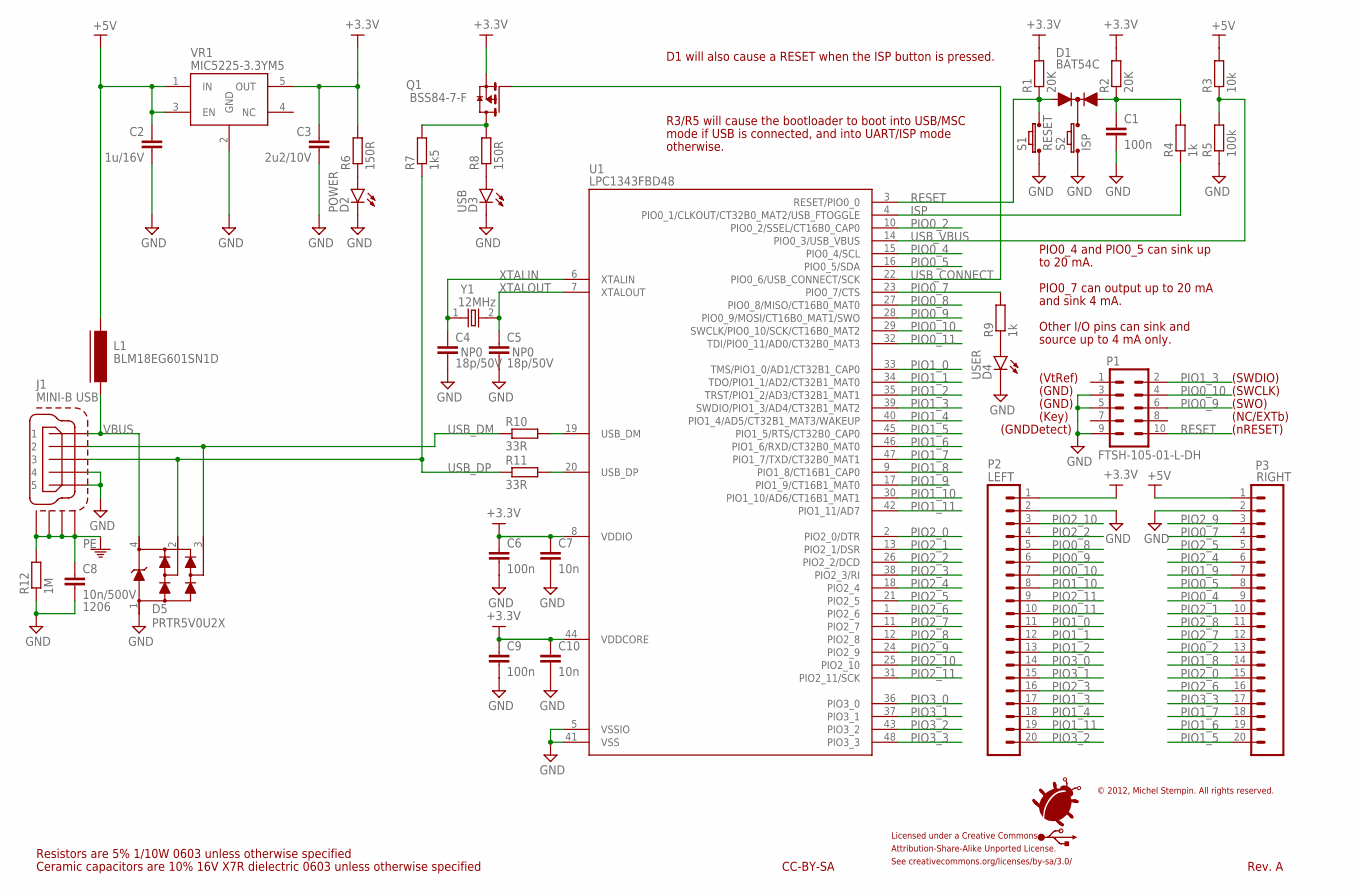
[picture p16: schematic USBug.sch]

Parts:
C1, C6, C9: 100n; CAP_0603
C2: 1u/16V; CAP_0603
C3: 2u2/10V; CAP_0603
C4, C5: 18p/50V; CAP_0603
C7, C10: 10n; CAP_0603
C8: 10n/500V; CAP_1206
D1: BAT54C; SOT23-R
D2: POWER; LED_0805
D3: USB; LED_0805
D4: USER; LED_0805
D5: PRTR5V0U2X; SOT143B
J1: MINI-B USB; UX60-MB-5ST
L1: BLM18EG601SN1D; FB_0603
LOGO: USBUG
P1: FTSH-105-01-L-DH
P2: LEFT; SPARKFUN_1X20_LOCK
P3: RIGHT; SPARKFUN_1X20_LOCK
Q1: BSS84-7-F; SOT23-R
R1, R2: 20K; RES_0603
R3: 10k; RES_0603
R4, R9: 1k; RES_0603
R5: 100k; RES_0603
R6, R8: 150R; RES_0603
R7: 1k5; RES_0603
R10, R11: 33R; RES_0603
R12: 1M; RES_0603
S1: RESET; ADTSM3
S2: ISP; ADTSM3
U1: LPC1343FBD48; LQFP48
VR1: MIC5225-3.3YM5; SOT23-5
Y1: 12MHz; NX5032GA

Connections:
+3.3V: C3.1, C6.1, C7.1, C9.1, C10.1, P2.1, Q1.2 (S), R1.2, R2.2, R6.2, U1.8 (VDDIO), U1.44 (VDDCORE), VR1.5 (OUT)
+5V: C2.1, L1.1, P3.1, R3.2, VR1.1 (IN), VR1.3 (EN)
GND: C1.2, C2.2, C3.2, C4.2, C5.2, C6.2, C7.2, C8.2, C9.2, C10.2, D2.C, D3.C, D4.C, D5.1, J1.4, J1.5, P1.3, P1.5, P1.9, P2.2, P3.2, R5.1, R12.1, S1.2, S2.2, U1.5 (VSSIO), U1.41 (VSS), VR1.2 (GND)
ISP: R4.1, U1.4 (PIO0_1/CLKOUT/CT32B0_MAT2/USB_FTOGGLE)
unnamed: D1.3 (C), S2.1
unnamed: C1.1, D1.2 (A2), R2.1, R4.2
unnamed: D2.A, R6.1
unnamed: D4.A, R9.1
unnamed: D3.A, R8.1
unnamed: Q1.3 (D), R7.2, R8.2
PE: C8.1, J1.M1, J1.M2, J1.M3, J1.M4, R12.2
PIO0_2: P3.13, U1.10 (PIO0_2/SSEL/CT16B0_CAP0)
PIO0_4: P3.9, U1.15 (PIO0_4/SCL)
PIO0_5: P3.8, U1.16 (PIO0_5/SDA)
PIO0_7: P3.4, R9.2, U1.23 (PIO0_7/CTS)
PIO0_8: P2.5, U1.27 (PIO0_8/MISO/CT16B0_MAT0)
PIO0_9: P1.6, P2.6, U1.28 (PIO0_9/MOSI/CT16B0_MAT1/SWO)
PIO0_10: P1.4, P2.7, U1.29 (SWCLK/PIO0_10/SCK/CT16B0_MAT2)
PIO0_11: P2.10, U1.32 (TDI/PIO0_11/AD0/CT32B0_MAT3)
PIO1_0: P2.11, U1.33 (TMS/PIO1_0/AD1/CT32B1_CAP0)
PIO1_1: P2.12, U1.34 (TDO/PIO1_1/AD2/CT32B1_MAT0)
PIO1_2: P2.13, U1.35 (TRST/PIO1_2/AD3/CT32B1_MAT1)
PIO1_3: P1.2, P2.17, U1.39 (SWDIO/PIO1_3/AD4/CT32B1_MAT2)
PIO1_4: P2.18, U1.40 (PIO1_4/AD5/CT32B1_MAT3/WAKEUP)
PIO1_5: P3.20, U1.45 (PIO1_5/RTS/CT32B0_CAP0)
PIO1_6: P3.19, U1.46 (PIO1_6/RXD/CT32B0_MAT0)
PIO1_7: P3.18, U1.47 (PIO1_7/TXD/CT32B0_MAT1)
PIO1_8: P3.14, U1.9 (PIO1_8/CT16B1_CAP0)
PIO1_9: P3.7, U1.17 (PIO1_9/CT16B1_MAT0)
PIO1_10: P2.8, U1.30 (PIO1_10/AD6/CT16B1_MAT1)
PIO1_11: P2.19, U1.42 (PIO1_11/AD7)
PIO2_0: P3.15, U1.2 (PIO2_0/DTR)
PIO2_1: P3.10, U1.13 (PIO2_1/DSR)
PIO2_2: P2.4, U1.26 (PIO2_2/DCD)
PIO2_3: P2.16, U1.38 (PIO2_3/RI)
PIO2_4: P3.6, U1.18 (PIO2_4)
PIO2_5: P3.5, U1.21 (PIO2_5)
PIO2_6: P3.16, U1.1 (PIO2_6)
PIO2_7: P3.12, U1.11 (PIO2_7)
PIO2_8: P3.11, U1.12 (PIO2_8)
PIO2_9: P3.3, U1.24 (PIO2_9)
PIO2_10: P2.3, U1.25 (PIO2_10)
PIO2_11: P2.9, U1.31 (PIO2_11/SCK)
PIO3_0: P2.14, U1.36 (PIO3_0)
PIO3_1: P2.15, U1.37 (PIO3_1)
PIO3_2: P2.20, U1.43 (PIO3_2)
PIO3_3: P3.17, U1.48 (PIO3_3)
RESET: D1.1 (A1), P1.10, R1.1, S1.1, U1.3 (RESET/PIO0_0)
USBD+: R10.2, U1.19 (USB_DM)
USBD-: R11.2, U1.20 (USB_DP)
USB_CONNECT: Q1.1 (G), U1.22 (PIO0_6/USB_CONNECT/SCK)
USB_DM: D5.3, J1.2, R10.1
USB_DP: D5.2, J1.3, R7.1, R11.1
USB_VBUS: R3.1, R5.2, U1.14 (PIO0_3/USB_VBUS)
VBUS: D5.4, J1.1, L1.2
XTALIN: C4.1, U1.6 (XTALIN), Y1.1
XTALOUT: C5.1, U1.7 (XTALOUT), Y1.2

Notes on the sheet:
Rev. A
PIO0_7 can output up to 20 mA
and sink 4 mA.
PIO0_4 and PIO0_5 can sink up
to 20 mA.
Other I/O pins can sink and
source up to 4 mA only.
D1 will also cause a RESET when the ISP button is pressed.
R3/R5 will cause the bootloader to boot into USB/MSC
mode if USB is connected, and into UART/ISP mode
otherwise.
© 2012, Michel Stempin. All rights reserved.
Licensed under a Creative Commons
Attribution-Share-Alike Unported License.
See creativecommons.org/licenses/by-sa/3.0/
(SWDIO)
(SWCLK)
(SWO)
(VtRef)
(GND)
(Key)
(NC/EXTb)
(GNDDetect)
(nRESET)
Ceramic capacitors are 10% 16V X7R dielectric 0603 unless otherwise specified
Resistors are 5% 1/10W 0603 unless otherwise specified
CC-BY-SA

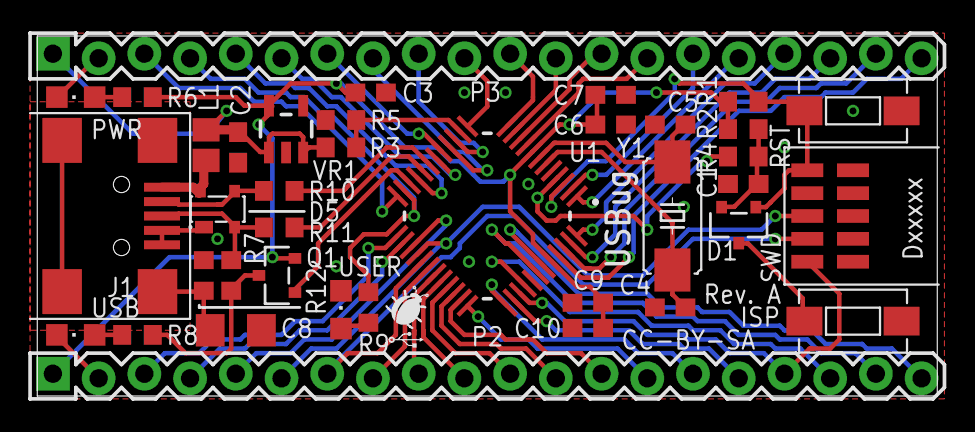
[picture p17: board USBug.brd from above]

Board: 2 copper layers, 50.0 x 20.0 mm, 39 parts (0 on the bottom side), 57 nets.

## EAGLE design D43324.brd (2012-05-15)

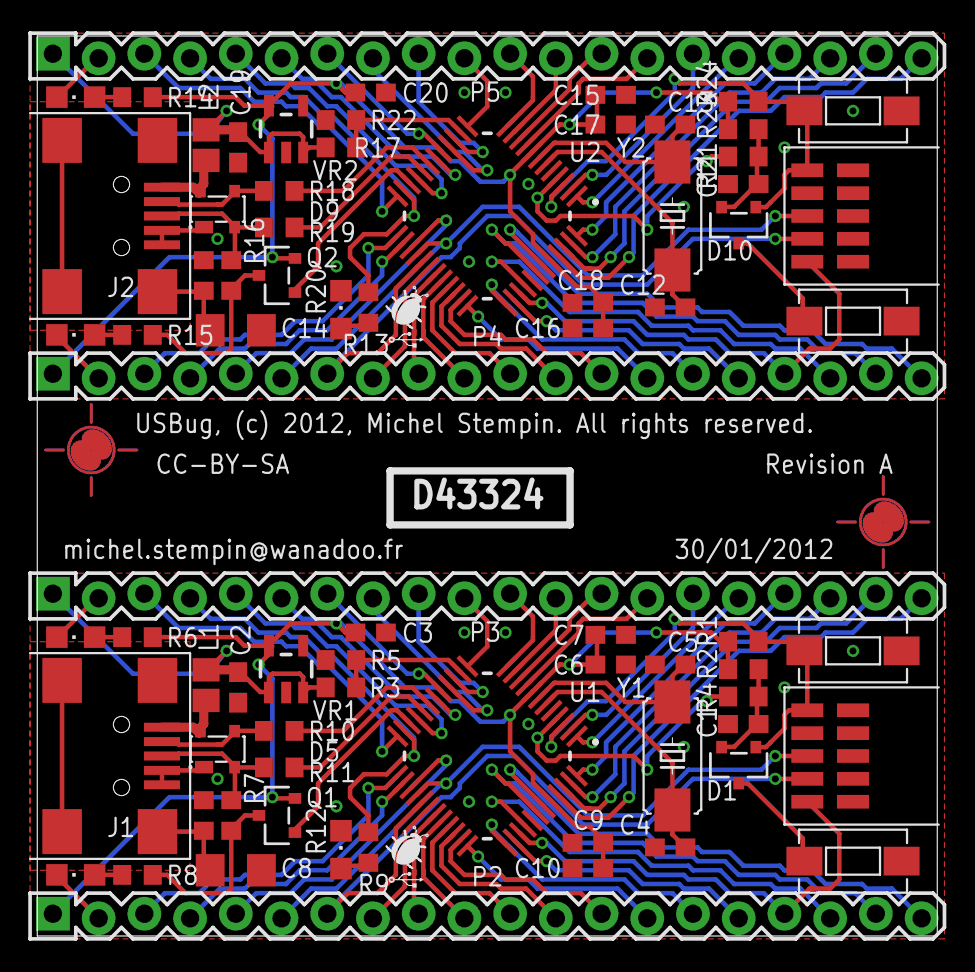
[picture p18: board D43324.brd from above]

Board: 2 copper layers, 50.0 x 50.0 mm, 80 parts (0 on the bottom side), 114 nets.

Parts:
C1, C6, C9, C11, C17, C18: 100n; CAP_0603
C2, C19: 1u/16V; CAP_0603
C3, C20: 2u2/10V; CAP_0603
C4, C5, C12, C13: 18p/50V; CAP_0603
C7, C10, C15, C16: 10n; CAP_0603
C8, C14: 10n/500V; CAP_1206
D1, D10: BAT54C; SOT23-R
D2, D7: POWER; LED_0805
D3, D8: USB; LED_0805
D4, D6: USER; LED_0805
D5, D9: PRTR5V0U2X; SOT143B
E$1, E$2: PASS-ROUND
E$3: USBUG
J1, J2: MINI-B USB; UX60-MB-5ST
L1, L2: BLM18EG601SN1D; FB_0603
P1, P6: FTSH-105-01-L-DH
P2, P4: LEFT; SPARKFUN_1X20_LOCK
P3, P5: RIGHT; SPARKFUN_1X20_LOCK
Q1, Q2: BSS84-7-F; SOT23-R
R1, R2, R23, R24: 20K; RES_0603
R3, R17: 10k; RES_0603
R4, R9, R13, R21: 1k; RES_0603
R5, R22: 100k; RES_0603
R6, R8, R14, R15: 150R; RES_0603
R7, R16: 1k5; RES_0603
R10, R11, R18, R19: 33R; RES_0603
R12, R20: 1M; RES_0603
S1, S4: RESET; ADTSM3
S2, S3: ISP; ADTSM3
U1, U2: LPC11U12FBD48; LQFP48
U$13: USBUG
VR1, VR2: MIC5225-3.3YM5; SOT23-5
Y1, Y2: 12MHz; NX5032GA

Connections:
+3.3V: C3.1, C6.1, C7.1, C9.1, C10.1, P2.1, Q1.2, R1.2, R2.2, R6.2, U1.8, U1.44, VR1.5
+3.3V1: C15.1, C16.1, C17.1, C18.1, C20.1, P4.1, Q2.2, R14.2, R23.2, R24.2, U2.8, U2.44, VR2.5
+5V: C2.1, L1.1, P3.1, R3.2, VR1.1, VR1.3
+5V1: C19.1, L2.1, P5.1, R17.2, VR2.1, VR2.3
EARTH: C8.1, J1.M1, J1.M2, J1.M3, J1.M4, R12.2
EARTH1: C14.1, J2.M1, J2.M2, J2.M3, J2.M4, R20.2
GND: C1.2, C2.2, C3.2, C4.2, C5.2, C6.2, C7.2, C8.2, C9.2, C10.2, D2.C, D3.C, D4.C, D5.1, J1.4, J1.5, P1.3, P1.5, P1.9, P2.2, P3.2, R5.1, R12.1, S1.2, S2.2, U1.5, U1.41, VR1.2
GND1: C11.2, C12.2, C13.2, C14.2, C15.2, C16.2, C17.2, C18.2, C19.2, C20.2, D6.C, D7.C, D8.C, D9.1, J2.4, J2.5, P4.2, P5.2, P6.3, P6.5, P6.9, R20.1, R22.1, S3.2, S4.2, U2.5, U2.41, VR2.2
ISP: R4.1, U1.4
ISP1: R21.1, U2.4
unnamed: D1.3, S2.1
unnamed: C1.1, D1.2, R2.1, R4.2
unnamed: D2.A, R6.1
unnamed: D4.A, R9.1
unnamed: Q2.3, R15.2, R16.2
unnamed: C11.1, D10.2, R21.2, R23.1
unnamed: D7.A, R14.1
unnamed: D6.A, R13.1
unnamed: D3.A, R8.1
unnamed: D8.A, R15.1
unnamed: D10.3, S3.1
unnamed: Q1.3, R7.2, R8.2
PIO0_1: P4.5, U2.27
PIO0_2: P3.13, U1.10
PIO0_3: P4.6, P6.6, U2.28
PIO0_4: P3.9, U1.15
PIO0_5: P3.8, U1.16
PIO0_6: P4.7, P6.4, U2.29
PIO0_7: P3.4, R9.2, U1.23
PIO0_8: P2.5, U1.27
PIO0_9: P1.6, P2.6, U1.28
PIO0_10: P1.4, P2.7, U1.29
PIO0_11: P2.10, U1.32
PIO0_12: P4.10, U2.32
PIO0_13: P5.4, R13.2, U2.23
PIO0_14: P5.8, U2.16
PIO0_15: P5.9, U2.15
PIO0_16: P5.13, U2.10
PIO1_0: P2.11, U1.33
PIO1_1: P2.12, U1.34
PIO1_2: P2.13, U1.35
PIO1_3: P1.2, P2.17, U1.39
PIO1_4: P2.18, U1.40
PIO1_5: P3.20, U1.45
PIO1_6: P3.19, U1.46
PIO1_7: P3.18, U1.47
PIO1_8: P3.14, U1.9
PIO1_9: P3.7, U1.17
PIO1_10: P2.8, U1.30
PIO1_11: P2.19, U1.42
PIO1_12: P5.14, U2.9
PIO1_13: P5.7, U2.17
PIO1_14: P4.8, U2.30
PIO1_15: P4.19, U2.42
PIO1_16: P5.20, U2.45
PIO1_17: P4.11, U2.33
PIO1_18: P4.12, U2.34
PIO1_19: P4.13, U2.35
PIO1_20: P4.17, P6.2, U2.39
PIO1_21: P4.18, U2.40
PIO1_22: P5.18, U2.47
PIO1_23: P5.19, U2.46
PIO2_0: P3.15, U1.2
PIO2_1: P3.10, U1.13
PIO2_2: P2.4, U1.26
PIO2_3: P2.16, U1.38
PIO2_4: P3.6, U1.18
PIO2_5: P3.5, U1.21
PIO2_6: P3.16, U1.1
PIO2_7: P3.12, U1.11
PIO2_8: P3.11, U1.12
PIO2_9: P3.3, U1.24
PIO2_10: P2.3, U1.25
PIO2_11: P2.9, U1.31
PIO2_12: P5.10, U2.13
PIO2_13: P4.4, U2.26
PIO2_14: P4.16, U2.38
PIO2_15: P5.6, U2.18
PIO2_16: P5.5, U2.21
PIO2_17: P5.16, U2.1
PIO2_18: P5.12, U2.11
PIO2_19: P5.11, U2.12
PIO2_20: P5.3, U2.24
PIO2_21: P4.3, U2.25
PIO2_22: P4.9, U2.31
PIO2_23: P5.15, U2.2
PIO3_0: P2.14, U1.36
PIO3_1: P2.15, U1.37
PIO3_2: P2.20, U1.43
PIO3_3: P3.17, U1.48
PIO3_4: P4.14, U2.36
PIO3_5: P4.15, U2.37
PIO3_6: P4.20, U2.43
PIO3_7: P5.17, U2.48
RESET: D1.1, P1.10, R1.1, S1.1, U1.3
RESET1: D10.1, P6.10, R24.1, S4.1, U2.3
USBD+: R10.2, U1.19
USBD+1: R18.2, U2.19
USBD-: R11.2, U1.20
USBD-1: R19.2, U2.20
USB_CONNECT: Q1.1, U1.22
USB_CONNECT1: Q2.1, U2.22
USB_DM: D5.3, J1.2, R10.1
USB_DM1: D9.3, J2.2, R18.1
USB_DP: D5.2, J1.3, R7.1, R11.1
USB_DP1: D9.2, J2.3, R16.1, R19.1
USB_VBUS: R3.1, R5.2, U1.14
USB_VBUS1: R17.1, R22.2, U2.14
VBUS: D5.4, J1.1, L1.2
VBUS1: D9.4, J2.1, L2.2
XTALIN: C4.1, U1.6, Y1.1
XTALIN1: C12.1, U2.6, Y2.1
XTALOUT: C5.1, U1.7, Y1.2
XTALOUT1: C13.1, U2.7, Y2.2

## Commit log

2012-05-15 First public release
    [D43324.GBL, D43324.GBO, D43324.GBP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]
2012-06-03 Deleted old USBUg DigiKey BOM. Added both Digikey and Farnell baskets.
    [USBug DigiKey.xlsx]
2012-07-10 Added Board-Comparison.jpg

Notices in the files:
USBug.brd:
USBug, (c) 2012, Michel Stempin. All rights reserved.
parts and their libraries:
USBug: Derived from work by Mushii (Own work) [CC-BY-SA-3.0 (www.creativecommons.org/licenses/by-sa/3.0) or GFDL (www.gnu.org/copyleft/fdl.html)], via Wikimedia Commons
